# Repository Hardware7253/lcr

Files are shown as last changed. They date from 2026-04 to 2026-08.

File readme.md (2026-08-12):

# LCR Meter
lcr_1

## Description
This LCR meter is capable of measuring complex impedance of various passive components and features auto-ranging.
Figure 1 shows the basic test circuit and provides an equation that can be used to calculate the impedance of the DUT.
This circuit + additional filtering and biasing is used within the LCR design.
The MCU software uses the pk-pk values of the sampled waveforms for magnitudes, and calculates the phase difference using in-phase and quadrature components of the multiplied current and test voltage waveforms (v3 & v2). The IQ components are low-pass-filtered, then their arctan is taken to find the phase difference.

lcr_circuit
Figure 1: Basic LCR testing circuit.

## Demos
lead_test
r_test_4r7
c_test_50n
c_test_220n
c_test_100u
l_test_10u
l_test_100u

## Additional photos
lcr_2
lcr_back

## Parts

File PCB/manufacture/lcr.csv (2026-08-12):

Reference | Qty | Value | Footprint | Datasheet | LCSC PART #
K1,K2,K3 | 3 | G6K-2 | Relay_SMD:Relay_DPDT_Omron_G6K-2F-Y | http://omronfs.omron.com/en_US/ecb/products/pdf/en-g6k.pdf | C47190
U8,U9,U10 | 3 | OPA2197xDGK | CustomFootprints:VSSOP-8_3x3mm_P0.65mm | http://www.ti.com/lit/ds/symlink/opa2197.pdf | C2867268
U7 | 1 | AD9833xRM | CustomFootprints:MSOP-10_3x3mm_P0.5mm | https://www.analog.com/media/en/technical-documentation/data-sheets/ad9833.pdf | C9652
D1,D2,D3 | 3 | LED | LED_SMD:LED_0603_1608Metric | https://www.lcsc.com/datasheet/C2286.pdf | C2286
C2,C3,C4,C5,C10,C17,C25,C26,C30,C37,C38,C40,C42,C43,C44 | 15 | 100n | Capacitor_SMD:C_0603_1608Metric | https://www.lcsc.com/datasheet/C14663.pdf | C14663
C7,C12,C13,C18,C19 | 5 | 1u | Capacitor_SMD:C_0603_1608Metric | https://www.lcsc.com/datasheet/C15849.pdf | C15849
C16,C20,C23,C24,C34 | 5 | 4u7 | Capacitor_SMD:C_0603_1608Metric | https://www.lcsc.com/datasheet/C19666.pdf | C19666
R2,R3,R4,R8,R10,R15,R16,R18 | 8 | 1k | Resistor_SMD:R_0603_1608Metric | https://www.lcsc.com/datasheet/C22548.pdf | C22548
R1,R7,R9,R25,R27 | 5 | 5k1 | Resistor_SMD:R_0603_1608Metric | https://www.lcsc.com/datasheet/C23186.pdf | C23186
R24,R26,R31 | 3 | 100k | Resistor_SMD:R_0603_1608Metric | https://www.lcsc.com/datasheet/C25803.pdf | C25803
R5,R12,R13,R30 | 4 | 10k | Resistor_SMD:R_0603_1608Metric | https://www.lcsc.com/datasheet/C25804.pdf | C25804
C6,C31,C33 | 3 | 10n | Capacitor_SMD:C_0603_1608Metric | https://www.lcsc.com/datasheet/C57112.pdf | C57112
C32,C36,C41 | 3 | 220n | Capacitor_SMD:C_0603_1608Metric | https://www.lcsc.com/datasheet/C64705.pdf | C64705
C1,C8,C9,C11,C21,C22,C27,C28,C29,C35,C39 | 11 | 10u | Capacitor_SMD:C_0603_1608Metric | https://www.lcsc.com/datasheet/C96446.pdf | C96446
R11,R19,R22,R28,R29,R32,R33,R34 | 8 | 100 | Resistor_SMD:R_0603_1608Metric | https://www.lcsc.com/datasheet/C105588.pdf | C105588
R17,R20,R21,R23 | 4 | 22k | Resistor_SMD:R_0603_1608Metric | https://www.lcsc.com/datasheet/C114065.pdf | C114065
R14 | 1 | 2k7 | Resistor_SMD:R_0603_1608Metric | https://www.lcsc.com/datasheet/C114612.pdf | C114612
R6 | 1 | 470k | Resistor_SMD:R_0603_1608Metric | https://www.lcsc.com/datasheet/C114622.pdf | C114622
SW1,SW2 | 2 | SW_Push | CustomFootprints:Korean Hroparts Elec K2-1107ST-A4DW-06 | https://www.lcsc.com/datasheet/C118141.pdf | C118141
D4,D5,D8,D9,D11,D12,D13 | 7 | CUS10S30 | Diode_SMD:D_SOD-323_HandSoldering | https://www.lcsc.com/datasheet/C146335.pdf | C146335
C14,C15 | 2 | 20p | Capacitor_SMD:C_0603_1608Metric | https://www.lcsc.com/datasheet/C326779.pdf | C326779
D6,D7,D10 | 3 | TVS | Diode_SMD:D_SOD-323_HandSoldering | https://www.lcsc.com/datasheet/C552583.pdf | C552583
TP2,TP8,TP9,TP13,TP14,TP15,TP16,TP17 | 8 | TestPoint | TestPoint:TestPoint_Keystone_5000-5004_Miniature | https://www.lcsc.com/datasheet/C5199801.pdf | C5199801
Q1,Q2,Q3 | 3 | NMOS | Package_TO_SOT_SMD:SOT-23 | https://www.lcsc.com/datasheet/C7429875.pdf | C7429875
J3,J4 | 2 | Probe + | CustomFootprints:Banana_Red | https://www.lcsc.com/datasheet/C7437326.pdf | C7437326
J5,J6 | 2 | Probe - | CustomFootprints:Banana_Black | https://www.lcsc.com/datasheet/C7437327.pdf | C7437327
PS1 | 1 | B0503S-1WR3 | Converter_DCDC:Converter_DCDC_Murata_MEE1SxxxxSC_THT | https://www.lcsc.com/datasheet/C7465187.pdf | C7465187
DS1 | 1 | SSD1315 | CustomFootprints:0.96 Inch OLED Display | https://www.lcsc.com/datasheet/C18723026.pdf | C18723027/C262645
Y1 | 1 | 8 MHz | Crystal:Crystal_SMD_5032-2Pin_5.0x3.2mm | https://www.lcsc.com/datasheet/C46613796.pdf | C46613796
Y2 | 1 | 25MHz | Oscillator:Oscillator_SMD_Abracon_ASE-4Pin_3.2x2.5mm | https://www.lcsc.com/datasheet/C49207939.pdf | C49207939
U2 | 1 | STM32G431CBT6 | Package_QFP:LQFP-48_7x7mm_P0.5mm | https://www.st.com/resource/en/datasheet/stm32g431cb.pdf | C529355
U5 | 1 | USBLC6-2SC6 | Package_TO_SOT_SMD:SOT-23-6 | https://www.st.com/resource/en/datasheet/usblc6-2.pdf | C7519
U3,U6 | 2 | TLV757P | Package_TO_SOT_SMD:SOT-23-5 | https://www.ti.com/lit/ds/symlink/tlv757p.pdf | C485517
U1 | 1 | TLV75801PDBV | Package_TO_SOT_SMD:SOT-23-5 | https://www.ti.com/lit/ds/symlink/tlv758p.pdf | C2877852
U4 | 1 | TPS22919DCK | Package_TO_SOT_SMD:SOT-363_SC-70-6 | https://www.ti.com/lit/ds/symlink/tps22919.pdf | C2149796
J2 | 1 | USB_C_Receptacle_USB2.0_16P | CustomFootprints:USB_TYPE-C-31-M-12 | https://www.usb.org/sites/default/files/documents/usb_type-c.zip | C165948

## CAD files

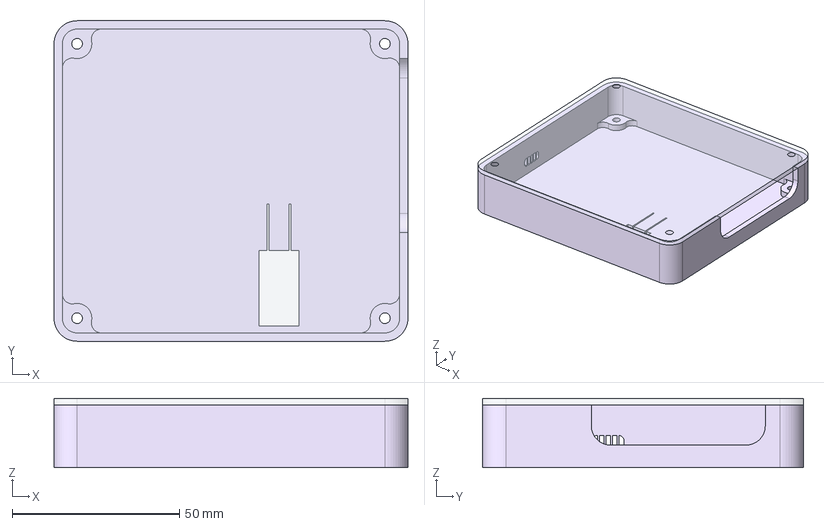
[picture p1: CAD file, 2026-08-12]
Case/Case.step
105.8 x 95.8 x 20.7 mm

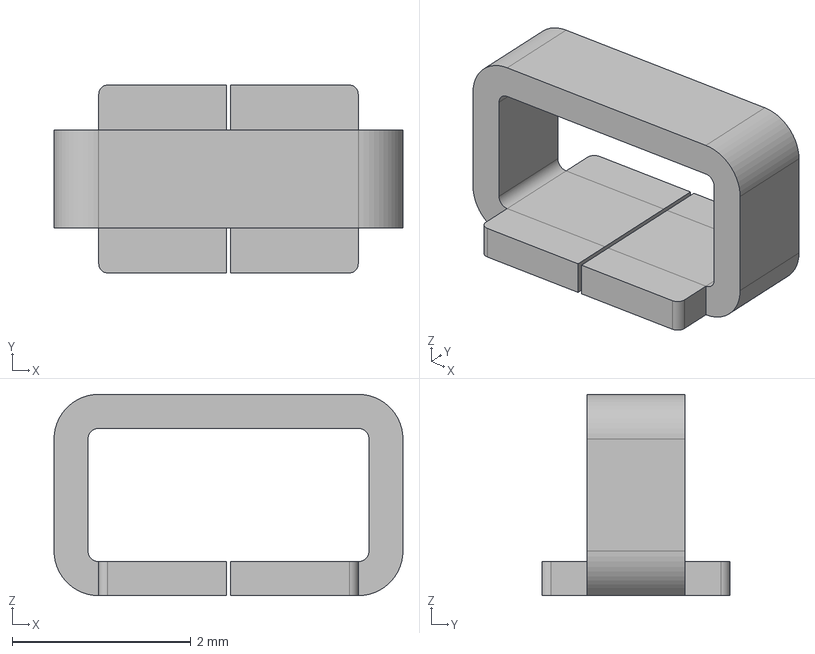
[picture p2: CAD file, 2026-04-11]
PCB/3D/TestPoint_Keystone_5019_Minature.step
3.90 x 2.10 x 2.25 mm

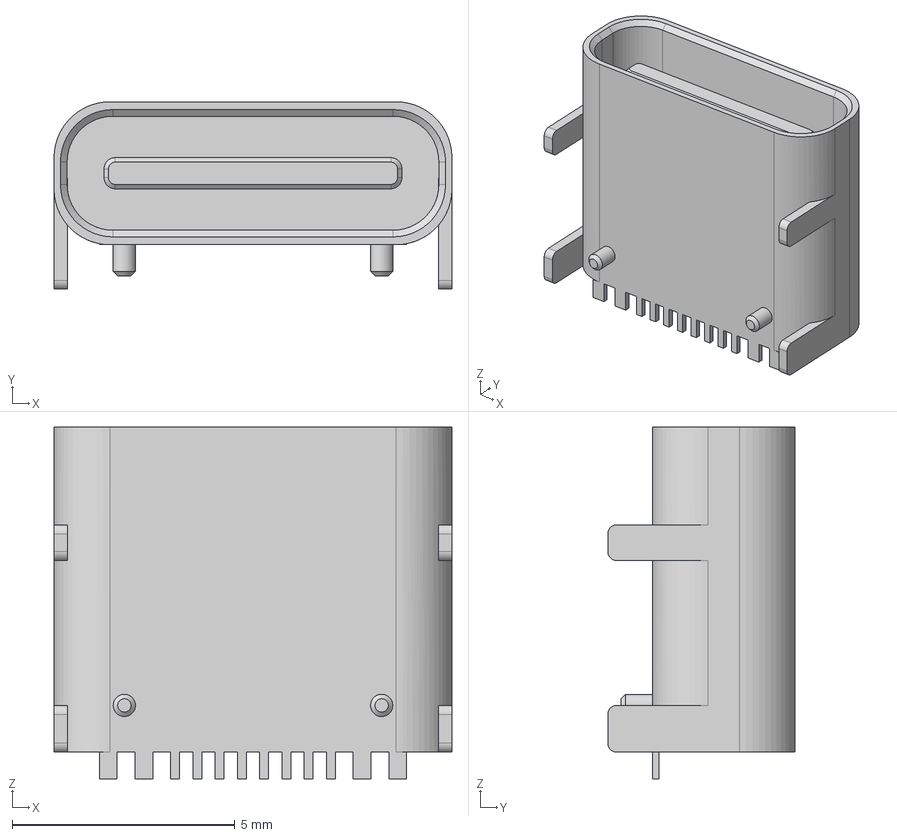
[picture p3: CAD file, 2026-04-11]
PCB/3D/HRO TYPE-C-31-M-12.step
8.94 x 4.21 x 7.90 mm

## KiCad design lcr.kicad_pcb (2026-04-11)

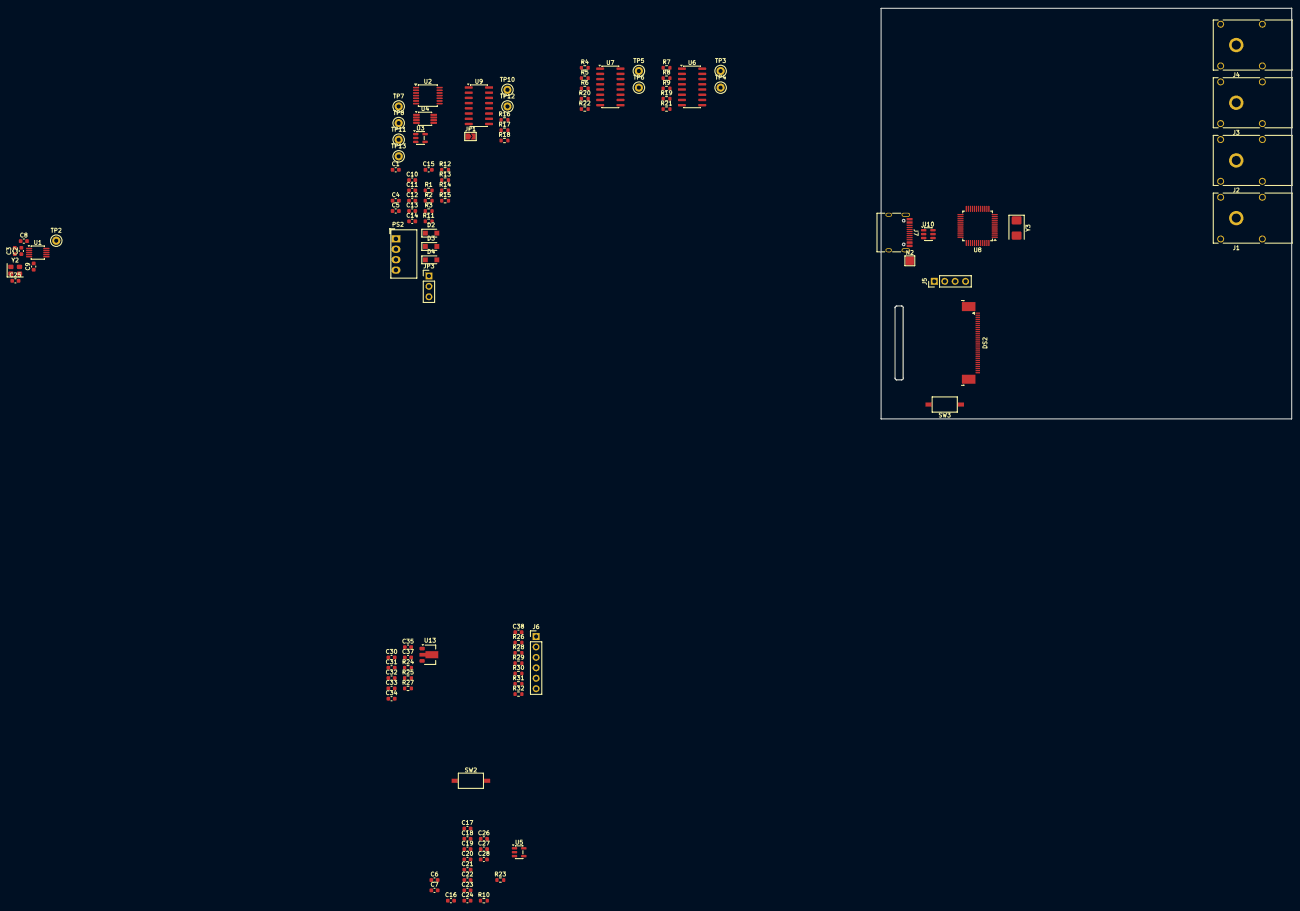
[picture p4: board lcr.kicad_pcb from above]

Board: 2 copper layers, 100.0 x 100.0 mm, 109 parts (1 on the bottom side), 71 nets, no tracks yet.

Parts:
C1, C10, C11: 220n; C_0603_1608Metric
C2, C8, C9, C12, C13, C14, C15, C21, C22, C23, C24, C26, C35: 100n; C_0603_1608Metric
C3, C4, C5, C6, C7, C17, C20, C33, C34, C37, C38: 10u; C_0603_1608Metric
C16, C19, C30, C31, C32: 1u; C_0603_1608Metric
C18, C25: 10n; C_0603_1608Metric
C27, C28: 20p; C_0603_1608Metric
D2, D3, D4: SMF6.5CA; Nexperia_CFP3_SOD-123W
DS2: SSD1315; 0.96 Inch OLED Display
J1, J2: Probe +; Banana_Cliff_FCR7350R_S16N-PC_Horizontal
J3, J4: Probe +; Banana_Cliff_FCR7350B_S16N-PC_Horizontal
J5: Conn_01x04_Pin; PinHeader_1x04_P2.54mm_Vertical
J6: Conn_01x06_Pin; PinHeader_1x06_P2.54mm_Vertical
J7: USB_C_Receptacle_USB2.0_14P; USB_TYPE-C-31-M-12
JP1: Jumper_2_Open; SolderJumper-2_P1.3mm_Open_TrianglePad1.0x1.5mm
JP3: Jumper_3_Bridged12; PinHeader_1x03_P2.54mm_Vertical
N2: Housing_Pad; TestPoint_Pad_2.0x2.0mm
PS2: B0503S-1WR3; Converter_DCDC_Murata_MEE1SxxxxSC_THT
R1, R2, R16, R18, R19, R20, R21, R22, R27: 10k; R_0603_1608Metric
R3, R24, R25: 2k7; R_0603_1608Metric
R4, R7: 0; R_0603_1608Metric
R5, R8, R10, R23: 5k1; R_0603_1608Metric
R6, R9, R17: 100k; R_0603_1608Metric
R11, R28, R29, R30, R31, R32: 1k; R_0603_1608Metric
R12, R13, R14, R15: 22k; R_0603_1608Metric
R26: 470k; R_0603_1608Metric
SW2, SW3: SW_Push; Korean Hroparts Elec K2-1107ST-A4DW-06
TP2, TP3, TP4, TP5, TP6, TP7, TP8, TP10, TP11, TP12, TP13: TestPoint; TestPoint_Keystone_5000-5004_Miniature
U1: AD9833xRM; MSOP-10_3x3mm_P0.5mm
U2: LMH6644MTX; TSSOP-14_4.4x5mm_P0.65mm
U3, U5: TLV75733PDBV; SOT-23-5
U4: LMH6643MMX; VSSOP-8_3x3mm_P0.65mm
U6, U7, U9: 74HC4051; SOIC-16_3.9x9.9mm_P1.27mm
U8: STM32G431CBT6; LQFP-48_7x7mm_P0.5mm
U10: USBLC6-2SC6; SOT-23-6
U13: UMW HT7836-A; SOT-89-3
Y2: 25MHz; Oscillator_SMD_Abracon_ASE-4Pin_3.2x2.5mm
Y3: 8 MHz; Crystal_SMD_5032-2Pin_5.0x3.2mm

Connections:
+2V5: C9.2, U1.3 (CAP/2.5V)
+3V3: C2.2, C3.2, C7.2, C8.1, C20.2, C21.1, C22.1, C23.1, C24.1, C25.1, C35.1, DS2.9 (VDD), DS2.11 (BS1), J5.1, R24.2, R25.2, R27.2, U1.2 (VDD), U5.5 (OUT), U8.1 (VBAT), U8.24 (VDD), U8.36 (VDD), U8.48 (VDD), Y2.1 (EN), Y2.4 (Vdd)
+3V3A: C4.2, C13.2, C14.2, C18.1, C19.1, JP3.3 (B), R12.2, R14.2, U2.4 (V+), U3.5 (OUT), U4.8 (V+), U6.16 (VCC), U7.16 (VCC), U8.21 (VDDA), U9.16 (VCC)
+3V6: C34.2, DS2.6 (VBAT), U13.3 (VO)
+5V: C5.2, C6.2, C33.2, J7.A4 (VBUS), J7.A9 (VBUS), J7.B4 (VBUS), J7.B9 (VBUS), PS2.2 (+Vin), U3.1 (IN), U3.3 (EN), U5.1 (IN), U5.3 (EN), U10.5 (VBUS), U13.2 (VI)
-3V3A: C12.1, C15.1, PS2.3 (-Vout), U2.11 (V-), U4.4 (V-), U6.7 (VEE), U7.7 (VEE), U9.7 (VEE)
/Analog Section/DDS_COMP: C8.2, U1.1 (COMP)
/Analog Section/DDS_HPF: C1.2, R1.1, U4.3 (+)
/Analog Section/DDS_MCLK: U1.5 (MCLK), Y2.3 (OUT)
/Analog Section/DDS_OUT: C1.1, TP2.1 (1_1), U1.10 (VOUT)
/Analog Section/Gain Selector/R_P1: JP1.1 (A), R11.2, TP12.1 (1_1), U2.6 (-), U9.3 (A)
/Analog Section/TST_OP_IN: JP3.2 (C), U4.5 (+)
/Analog Section/TST_OP_OUT: TP13.1 (1_1), U4.6 (-), U4.7
/Analog Section/dut_cur_1: C11.1, R4.1, R5.1, R6.1, TP6.1 (1_1), U2.1
/Analog Section/dut_curr_2: C11.2, R14.1, R15.2, U2.12 (+)
/Analog Section/dut_test_1: C10.1, R16.1, R17.1, TP10.1 (1_1), U2.7
/Analog Section/dut_test_2: C10.2, R12.1, R13.2, U2.10 (+)
/Analog Section/post_dut: D4.2 (A2), J3.1 (Pin_1_1), J4.1 (Pin_1_1), TP5.1 (1_1), U2.2 (-), U7.3 (A)
/Analog Section/pre_dut: D2.2 (A2), J1.1 (Pin_1_1), R7.1, R8.1, R9.1, TP3.1 (1_1)
/Analog Section/v_test: D3.2 (A2), J2.1 (Pin_1_1), R11.1, TP11.1 (1_1)
/C1N: C31.1, DS2.5 (C1N)
/C1P: C31.2, DS2.4 (C1P)
/C2N: C32.1, DS2.3 (C2N)
/C2P: C32.2, DS2.2 (C2P)
/CC1: J7.A5 (CC1), R10.1
/CC2: J7.B5 (CC2), R23.1
/CD+: J7.A6 (D+), J7.B6 (D+), U10.3 (I/O2)
/CD-: J7.A7 (D-), J7.B7 (D-), U10.1 (I/O1)
/DISP_IREF: DS2.26 (IREF), R26.1
/DISP_VCC: C37.2, DS2.28 (VCC)
/DISP_VCOMH: C38.2, DS2.27 (VCOMH)
/SW_CLK: J5.3, U8.38 (PA14)
/SW_DIO: J5.2, U8.37 (PA13)
BUT_1: R28.1, U8.44 (PB7)
BUT_2: R29.1, U8.43 (PB6)
BUT_3: R30.1, U8.42 (PB5)
BUT_4: R31.1, U8.41 (PB4)
BUT_5: R32.1, U8.40 (PB3)
DDS_AMPLIFIED: R2.2, TP4.1 (1_1), U4.1, U6.3 (A)
DDS_SCLK: U1.7 (SCLK), U8.27 (PB13)
DDS_SDATA: U1.6 (SDATA), U8.29 (PB15)
DISP_SCL: DS2.18 (D0), R24.1, U8.31 (PA9)
DISP_SDA: DS2.19 (D1), DS2.20 (D2), R25.1, U8.30 (PA8)
GND: C2.1, C3.1, C4.1, C5.1, C6.1, C7.1, C9.1, C12.2, C13.1, C14.1, C15.2, C16.2, C17.2, C18.2, C19.2, C20.1, C21.2, C22.2, C23.2, C24.2, C25.2, C26.2, C27.2, C28.2, C30.2, C33.1, C34.1, C35.2, C37.1, C38.1, D2.1 (A1), D3.1 (A1), D4.1 (A1), DS2.1 (GND), DS2.8 (VSS), DS2.10 (BS0), DS2.13 (~CS), DS2.15 (D/~C), DS2.29 (VLSS), DS2.30 (GND), J5.4, J6.1, J7.A1 (GND), J7.A12 (GND), J7.B1 (GND), J7.B12 (GND), JP3.1 (A), PS2.1 (-Vin), PS2.4 (+Vout), R1.2, R3.1, R10.2, R13.1, R15.1, R18.1, R19.1, R20.1, R21.1, R22.1, R23.2, R26.2, SW2.1, SW3.1, U1.4 (DGND), U1.9 (AGND), U2.3 (+), U2.5 (+), U3.2 (GND), U5.2 (GND), U6.6 (~E), U6.8 (GND), U6.9 (S2), U7.6 (~E), U7.8 (GND), U7.9 (S2), U8.19 (VSSA), U8.23 (VSS), U8.35 (VSS), U8.47 (VSS), U9.6 (~E), U9.8 (GND), U9.9 (S2), U9.10 (S1), U10.2 (GND), U13.1 (GND), Y2.2 (GND)
NRST: C26.1, SW2.2, U8.7 (PG10)
unnamed: J6.2, R28.2, SW3.2
unnamed: J6.3, R29.2
unnamed: J6.4, R30.2
unnamed: J6.5, R31.2
unnamed: J6.6, R32.2
unnamed: JP1.2 (B), R16.2, U9.14 (A1)
unnamed: R2.1, R3.2, U4.2 (-)
unnamed: R9.2, U6.13 (A0)
unnamed: R8.2, U6.14 (A1)
unnamed: R7.2, U6.15 (A2)
unnamed: R6.2, U7.13 (A0)
unnamed: R5.2, U7.14 (A1)
unnamed: R4.2, U7.15 (A2)
unnamed: R17.2, U9.13 (A0)
OSC_IN: C27.1, U8.5 (PF0), Y3.2
OSC_OUT: C28.1, U8.6 (PF1), Y3.1
RANGE_S0: R21.2, R22.2, U6.11 (S0), U7.11 (S0), U8.12 (PA4)
RANGE_S1: R19.2, R20.2, U6.10 (S1), U7.10 (S1), U8.11 (PA3)
TEST_GAIN_S: R18.2, U8.10 (PA2), U9.11 (S0)
USB_D+: U8.34 (PA12), U10.4 (I/O2)
USB_D-: U8.33 (PA11), U10.6 (I/O1)
VREF+: C16.1, C17.1, U8.20 (VREF+)
dut_cur_3: TP7.1 (1_1), U2.13 (-), U2.14, U8.13 (PA5)
dut_test_3: TP8.1 (1_1), U2.8, U2.9 (-), U8.16 (PB0)
~DDS_FSYNC: U1.8 (~FSYNC), U8.26 (PB12)
~DISP_RES: C30.1, DS2.14 (~RES), R27.1

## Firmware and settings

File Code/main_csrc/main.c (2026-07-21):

#include <stdint.h>
#include <stdbool.h>

#include "stm32g4xx.h"
#include "stm32g4xx_hal.h"
#include "stm32g4xx_hal_conf.h"

#include "system.h"
#include "software_timer.h"
#include "blocking_delay.h"

#include "dut_measure.h"
#include "lcr_math.h"

#include "ui.h"
#include "buttons.h"

#define BUTTON_POLL_HZ 200
#define UI_UPDATE_HZ 10
#define HZ_TO_MS(hz) (1000U / (hz))

static uint32_t button_poll_last_run_ms = 0;
static uint32_t ui_update_last_run_ms = 0;

int main(void) {
    HAL_Init();
    init_clocks();
    init_blocking_delay();
    init_buttons();
    init_ui();

    while (true) {

        // Poll buttons
        if (HAL_GetTick() - button_poll_last_run_ms >= HZ_TO_MS(BUTTON_POLL_HZ)) {
            poll_buttons();
            button_poll_last_run_ms = HAL_GetTick();
            
        }

        // Update UI
        if (HAL_GetTick() - ui_update_last_run_ms >= HZ_TO_MS(UI_UPDATE_HZ)) {
            run_ui();
            ui_update_last_run_ms = HAL_GetTick();
        }
    }

    return 0;
}

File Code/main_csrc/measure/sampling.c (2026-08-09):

#include <string.h>
#include "sampling.h"
#include "stm32g4xx_hal.h"
#include "system.h"
#include "blocking_delay.h"
#include "ad9833.h"

#define DMA_CLK_EN              __HAL_RCC_DMA1_CLK_ENABLE(); __HAL_RCC_DMAMUX1_CLK_ENABLE

// ADC for measuring test waveform
#define TEST_ADC                ADC2
#define TEST_ADC_CLK_EN         __HAL_RCC_ADC12_CLK_ENABLE
#define TEST_ADC_CHANNEL        ADC_CHANNEL_13
#define TEST_DMA_REQUEST        DMA_REQUEST_ADC2
#define TEST_DMA_INST           DMA1_Channel2
#define TEST_DMA_IRQn           DMA1_Channel2_IRQn 
#define TEST_DMA_ISR            DMA1_Channel2_IRQHandler

// ADC for measuring current waveform
#define CURR_ADC                 ADC1 
#define CURR_ADC_CLK_EN          __HAL_RCC_ADC12_CLK_ENABLE
#define CURR_ADC_CHANNEL         ADC_CHANNEL_15
#define CURR_DMA_REQUEST         DMA_REQUEST_ADC1
#define CURR_DMA_INST            DMA1_Channel1 
#define CURR_DMA_IRQn            DMA1_Channel1_IRQn
#define CURR_DMA_ISR             DMA1_Channel1_IRQHandler

#define TEST_PIN                 GPIO_PIN_5
#define TEST_PIN_BUS             GPIOA
#define TEST_PIN_CLK_EN          __HAL_RCC_GPIOB_CLK_ENABLE 

#define CURR_PIN                 GPIO_PIN_0
#define CURR_PIN_BUS             GPIOB
#define CURR_PIN_CLK_EN          __HAL_RCC_GPIOA_CLK_ENABLE 

// Timer peripheral to trigger ADC conversions
#define TIM_INST                TIM3
#define TIM_CLK_EN              __HAL_RCC_TIM3_CLK_ENABLE
#define ADC_EXTERNALTRIG        ADC_EXTERNALTRIG_T3_TRGO

// SPI for sending data to DDS
#define SPI_INST                SPI2
#define SPI_BAUDRATE            SPI_BAUDRATEPRESCALER_256
#define SPI_CLK_EN              __HAL_RCC_SPI2_CLK_ENABLE
#define SPI_PIN_CLK_EN          __HAL_RCC_GPIOB_CLK_ENABLE
#define SPI_PIN_AF              GPIO_AF5_SPI2

#define SPI_CLK_PIN             GPIO_PIN_13
#define SPI_CLK_PIN_BUS         GPIOB

#define SPI_MOSI_PIN            GPIO_PIN_15
#define SPI_MOSI_PIN_BUS        GPIOB

#define SPI_FSYNC_PIN           GPIO_PIN_12
#define SPI_FSYNC_PIN_BUS       GPIOB

#define TIM_BASE_CLK            104000000UL
#define DDS_MCLK                25000000UL

static SPI_HandleTypeDef hspi;
static TIM_HandleTypeDef htim;

static DMA_HandleTypeDef hdma_test;
static DMA_HandleTypeDef hdma_curr;

static ADC_HandleTypeDef hadc_test;
static ADC_HandleTypeDef hadc_curr;

static bool test_buf_full = false;
static bool curr_buf_full = false;

// Struct for setting up timer period for ADC read and ADC sample times
typedef struct {
    uint16_t prescaler;
    uint16_t period;
    uint32_t adc_sample_time;
    uint32_t test_f;
} test_frequency_conf_t;


// Macro for initialising test_frequency_conf_t struct
// TIM trigger rate is SAMPLES_PER_PERIOD * test_freq,
// so the provided prescaler frequency must be a multiple of SAMPLES_PER_PERIOD * test_freq
#define TEST_CONFIG(prescaler_freq, test_freq, sample_time) \
{ \
    .prescaler = __HAL_TIM_CALC_PSC(TIM_BASE_CLK, prescaler_freq), \
    .period = __HAL_TIM_CALC_PERIOD( \
        TIM_BASE_CLK, \
        __HAL_TIM_CALC_PSC(TIM_BASE_CLK, prescaler_freq), \
        (test_freq * SAMPLES_PER_PERIOD)), \
    .adc_sample_time = (sample_time), \
    .test_f = (test_freq), \
}

// Test frequency configurations for the ADC trigger timer and DDS
// Indexed by the value of a test_frequency_t enum
static const test_frequency_conf_t TEST_CONFIGS[NO_OF_TEST_FREQUENCIES] = {
    #define PRESCALER_HZ 1600000 // 1.6 MHz (easily divisible to get test_freq * 16 trigger rates)

    [TF_100KHZ] = TEST_CONFIG(20800000, 100000, ADC_SAMPLETIME_12CYCLES_5),
    [TF_10KHZ] = TEST_CONFIG(PRESCALER_HZ, 10000, ADC_SAMPLETIME_92CYCLES_5),
    [TF_1KHZ] = TEST_CONFIG(PRESCALER_HZ, 1000, ADC_SAMPLETIME_247CYCLES_5),
    [TF_100HZ] = TEST_CONFIG(PRESCALER_HZ, 100, ADC_SAMPLETIME_640CYCLES_5),
};

// Spi write function for ad9833
static void spi_write_ad9833(uint16_t val) {
    HAL_GPIO_WritePin(SPI_FSYNC_PIN_BUS, SPI_FSYNC_PIN, GPIO_PIN_RESET);
    HAL_SPI_Transmit(&hspi, (uint8_t*)(&val), 1, 10);
    delay_us(2);
    HAL_GPIO_WritePin(SPI_FSYNC_PIN_BUS, SPI_FSYNC_PIN, GPIO_PIN_SET);
    delay_us(2);
}

static const ad9833_t AD9833 = {
    .spi_write = spi_write_ad9833,
    .mclk_speed = DDS_MCLK,
};


// Initialises last common settings for ADC and DMA then inits and links ADC and DMA
// Assumes other required config is already done
static void init_adc_dma(DMA_HandleTypeDef *hdma, ADC_HandleTypeDef *hadc) {

    // Config DMA
    hdma->Init.Direction = DMA_PERIPH_TO_MEMORY;
    hdma->Init.PeriphInc = DMA_PINC_DISABLE;
    hdma->Init.MemInc = DMA_MINC_ENABLE;
    hdma->Init.PeriphDataAlignment = DMA_PDATAALIGN_HALFWORD;
    hdma->Init.MemDataAlignment = DMA_MDATAALIGN_WORD;
    hdma->Init.Mode = DMA_NORMAL;
    hdma->Init.Priority = DMA_PRIORITY_MEDIUM;

    // Config ADC
    hadc->Init.Resolution = ADC_RESOLUTION_12B;
    hadc->Init.ClockPrescaler = ADC_CLOCK_SYNC_PCLK_DIV2;
    hadc->Init.DataAlign = ADC_DATAALIGN_RIGHT;
    hadc->Init.GainCompensation = 0;
    hadc->Init.ScanConvMode = ADC_SCAN_DISABLE;
    hadc->Init.EOCSelection = ADC_EOC_SINGLE_CONV;
    hadc->Init.LowPowerAutoWait = DISABLE;
    hadc->Init.ExternalTrigConvEdge = ADC_EXTERNALTRIGCONVEDGE_RISING;
    hadc->Init.NbrOfConversion = 1;
    hadc->Init.ScanConvMode = DISABLE;
    hadc->Init.ContinuousConvMode = DISABLE;
    hadc->Init.DiscontinuousConvMode = DISABLE;
    hadc->Init.DMAContinuousRequests = DISABLE;
    hadc->Init.Overrun = ADC_OVR_DATA_PRESERVED; 
    hadc->Init.OversamplingMode = DISABLE;

    error_handler_msg(HAL_DMA_Init(hdma), "Failed to init DMA");
    error_handler_msg(HAL_ADC_Init(hadc), "Failed to init ADC");

    // Use ADC independent mode
    ADC_MultiModeTypeDef mm_cfg = {
        .Mode = ADC_MODE_INDEPENDENT,
    };

    // Ignore HAL_ERROR, because an error is returned for ADC2 since it would be a slave in multimode
    HAL_ADCEx_MultiModeConfigChannel(hadc, &mm_cfg); 

    __HAL_LINKDMA(hadc, DMA_Handle, *hdma);
}

// Used for getting the frequency in Hz out of the test_frequency_t enum
uint32_t get_test_frequency_hz(test_frequency_t tf) {
    return TEST_CONFIGS[tf].test_f;
}
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

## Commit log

2026-04-11 First commit
    Commiting before adding LPF
    [HRO TYPE-C-31-M-12.step, TestPoint_Keystone_5019_Minature.step, analog_section.kicad_sch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]
2026-04-12 Did some routing
    Commiting before changing display from i2c to spi
    [analog_section.kicad_sch, gain_selector.kicad_sch, lcr.kicad_sch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]
2026-04-12 Done
    Schematics and PCB are "done".
    Meaning I've just finished but need to review
    the design before it's ready to order.
    [analog_section.kicad_sch, gain_selector.kicad_sch, lcr.kicad_sch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]
2026-04-13 Added polish
    [analog_section.kicad_sch, gain_selector.kicad_sch, lcr.kicad_sch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]
2026-04-25 Changed range resistor selector design
    Changed range resistor selector from an analog mux
    to a MOSFET BPS design. This should improve on resistance, linearity,
    and temperature stability for the range resistors.
    [analog_section.kicad_sch, gain_selector.kicad_sch, lcr.kicad_sch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]
2026-04-27 Started new layout
    Range resistors now use MOSFET BPS.
    Currently there's no protection for over voltage on the opamp or mcu
    inputs, so that needs to be done.
    [analog_section.kicad_sch, lcr.kicad_sch, range_resistors.kicad_sch]
2026-05-06 Added protection to MCU analog inputs
    DUT and test voltages now use clamping diodes to protect the MCU from
    voltages less than 0V and greater than 3.3V.
    Started laying out again, but thinking of trying something different
    with the layou of the range resistors around the 1st opamp.
    [analog_section.kicad_sch, gain_selector.kicad_sch, lcr.kicad_sch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]
2026-05-06 Done new layout
    Now need to polish again. Also should test BPS
    in the flesh and innevetably scrap half the current schematic
    and layout when it doesn't work as expected.
    [lcr.kicad_sch]
2026-05-07 Polished PCB
    [analog_section.kicad_sch]
2026-05-15 Added gate drive current limiting resistors
    [analog_section.kicad_sch, gain_selector.kicad_sch, lcr.csv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]
2026-05-16 Add prototype code
    Code was for a breadboard prototype with a development board, but should
    be useful for the final design.
    [HRO TYPE-C-31-M-12.step, TestPoint_Keystone_5019_Minature.step, analog_section.kicad_sch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]
2026-05-20 Added case design for 3d printing
    [Case.step, lcr.step]
2026-05-23 Changed code to work on final hardware
    The code now uses the stm32g4xx C HAL, as opposed to the old stm32f4xx
    HAL used for the breadboard prototype. I don't have hardware at this
    point so I can't test, the sampling code at this point is placeholder
    that likely needs fixing. Anyway it compiles.
    [main.c, sampling.c, system.c]
2026-06-03 Fixed some PCB bugs
    The OLED display ribbon cable folded the wrong way so the screen faced
    down, so I fixed that. Also made vias untented, made diodes
    easier to hand solder, and added ground test hook.
    The case CAD still needs to be updated.
    [analog_section.kicad_sch, lcr.csv, lcr.kicad_sch]
2026-06-09 Fixed gate drive comp ref
    Resistors in the voltage divider were the wrong way around, now it's
    correct. Also fixed the linker script, so the compiled code now uploads
    to the board. Verified DDS works, and LMH6643 has 21.56 ohm output
    impedance at DC. CAD still need updating.
    [analog_section.kicad_sch, lcr.csv]
2026-06-16 Added extra configuration for TIM, ADCs and DMAs
    I think the ADC clock speed needs adjusting
2026-06-20 Sampling now works correctly
    Enabling the dma mux clock and enabling internal voltage reference where
    previously missing. Now these are implemented and things are working
    enough that a device can be measured.
    [main.c, sampling.c, system.c]
2026-06-26 Fixed OLED display hardware and code
    On the schematic, the OLED pin D2 was left NC, but needed to be tied to
    D1. Also the u8g2 SPI code from the last commit was incorrect, as it
    didn't use 9-bit SPI mode which is necessary for 3-wire SPI communcation
    with the display. I fixed this, and also modified the hardware to allow
    4-wire and 3-wire SPI. I'll change the code over to 4-wire when I order
    new PCBs.
    [lcr.kicad_sch]
2026-06-30 Range resistors now use signal relays
    Most of the analog section layout was completely overhauled to fit this
    change.
    [analog_section.kicad_sch, lcr.csv, lcr.kicad_sch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]
2026-06-30 Removed old schematic sheets
    [gain_selector.kicad_sch, range_resistors.kicad_sch]
2026-07-01 Fixed unconnected IC
    The 3V3A regulator didn't have the 5V power supply attached.
    Also moved the oled intended position closer to the ribbon connector and
    removed unused footprints.
2026-07-01 Updated silkscreen
    Changed around the position of some reference designators on the
    silkscreen.
2026-07-02 Added code for UI, and more automated measuring
    Now there's a basic task scheduler to poll buttons and update UI at
    different rates. The user is able to trigger a measurement, and the
    display shows them the results. This functionality is implemented by
    ui.c. Also added code for range and gain resistors controlled by relays.
    The only thing to do at this point is to be able to find the correct
    combination of range/gain resistor automatically.
    [buttons.c, display.c]
2026-07-04 Added range resistor finding code
    Currently untested
2026-07-21 Changed opamps
    Changed opamps to OPA2197, which has higher open loop gain and much
    lower GBW. This opamp should be much more forgiving of parasitic
    capacitance and hopefully solve the ringing issue.
    Also fixed MOSFET orientation issue which has plagued this design until
    now, no wonder the BPS didn't work.
    Additionally changed firmware to use the new version of the button
    debouncing module from the embedded_c_modules repo.
    [analog_section.kicad_sch, lcr.csv, lcr.kicad_sch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]
2026-08-06 Fixed firmware pin assignment error
    Previously the ADC inputs for the DUT test and current waveforms
    were mixed up. After this fix, and changing opamps the device is able to
    measure complex impedances somewhat succesfully.
    Additionally updated MCU part of the schematic to use alternate pin
    names. Also made all instances of 'dut' related to the current waveform
    say 'curr' instead in the firmware.
    [analog_section.kicad_sch, lcr.kicad_sch]
2026-08-09 Improved noise detection
    Noise is now detected by counting zero crossings of the test and current
    sine waves. If there are too many zero crossings then the signal is
    noisy.
    Also fixed a bug where range resistor and gain resistor pointers weren't
    set properly when the find_range_gain_resistors function in
    dut_measure.c returned.
    [range_resistor.c, sampling.c]
2026-08-12 Added soft-start
    Also added new case step files
    [Case.step, analog_section.kicad_sch, lcr.csv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]
